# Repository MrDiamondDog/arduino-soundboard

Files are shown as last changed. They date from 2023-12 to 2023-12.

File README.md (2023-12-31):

# Arduino Soundboard

A soundboard made for an Arduino Mega 2560 that connects to your PC to adjust the volume of applications. 

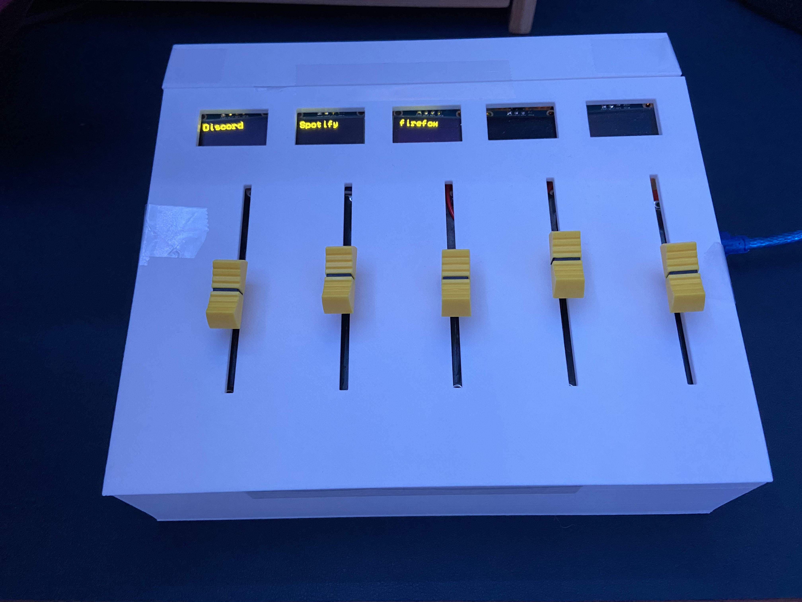
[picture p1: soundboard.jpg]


## How to make

There are a few steps required... and some money.

If you plan on making this, please read the whole document to fully understand what and how you are making this.

### Ingredients

-   3D Printer (for case)
-   Arduino Mega 2560
-   Breadboard
-   \>20x M/F Jumper Wires
-   5x [10K Logarithmic Slide Potentiometer](https://www.amazon.com/dp/B01CZVZ16O)
-   5x [0.96 inch 128x64 OLED LCD I2C Screens](https://www.amazon.com/dp/B085WCRS7C)
-   Constant USB connection to computer

### Steps

1. Clone this repo
2. Arduino Setup
    1. Install [Arduino IDE](https://www.arduino.cc/en/software)
    2. Open `arduino/arduino.ino` in the IDE
    3. Install all libraries from `arduino/libraries/`
        - To do this, use the IDE and navigate to `Sketch > Include Libraries > Add .ZIP Library...` and select the `.zip` files in the `libraries` folder.
    4. Connect the Arduino to your computer via USB
    5. Select the Arduino Mega 2560 and port in the IDE
    6. Upload the code to the Arduino
3. 3D Printing
    1. Download the STL file from [here](case.md)
    2. Print it (any color, any filament, it doesn't matter)
4. Assembly (this requires _some_ knowledge of electronics)
    1. Put the Arduino in the case, so the hole lines up with the port
    2. Adhere the back of your breadboard to the back inside part of the case
    3. Put all of the potentiometers (take off the caps) on the pedestals and adhere them to said pedsatals (I used tape)
    4. Wire all of the potentiometers to the arduino, where the first one is connected to A10, then second to A11, etc.
    5. Wire all of the potentiometers to power (5V) and ground on the breadboard.
    6. Adhere the screens to the holes (more tape)
    7. Wire all the screens so that the first one's SCL is connected to A0, SDA to A1, second one's SCL to A2, SDA to A3, etc.
    8. Connect the screens to power (5V) and ground on the breadboard.
    9. Adhere the screens to the lid (more tape)
    10. Put the lid on the case (this may require some force), make sure the potentiometers are in the holes
    11. Adhere the lid to the case (more tape)
    12. Almost there, put the caps on the potentiometers and put the small lid on the case
    13. Connect Arduino to computer via USB
5. PC Setup
    1. Install [Node.js](https://nodejs.org/en/) and make sure it came with `npm`
    2. Run `npm i` to install all required packages
    3. Copy `node_modules/@serialport/bindings-cpp/prebuilds` into `out` (make the out folder if it doesn't exist)
    4. Make sure your Arduino is connected to your computer via USB and running with the Arduino program
    5. Run `npm start` to start the program
    6. Make sure the program is working properly by moving the sliders and hearing the volume of the application change
6. Adding to start
    1. After running the commands from before and making sure it is working, run `npm run package` in your terminal.
    2. Change the path on the 3rd line of `soundboard_nogui.vbs` to the path of `out`.
    3. Put `soundboard_nogui.vbs` to your startup folder (Windows: `C:\Users\<user>\AppData\Roaming\Microsoft\Windows\Start Menu\Programs\Startup`)

### Additional Notes

-   You can change all of the values from `config.json`, you must restart after changing any heartbeat related values.
    -   `blacklistProcesses`: A list of processes to ignore, to add one, just add the exact name of the process from the soundboard to the array.
    -   `priorityProcesses`: A list of processes to give priority to, to add one, just add the exact name of the process from the soundboard to the array. This will move that process to the front.
    -   `heartbeatInterval`: The interval in milliseconds to send a heartbeat to the Arduino. This is used to make sure the Arduino is still connected.
    -   `heartbeatTimeout`: The timeout in milliseconds to wait for a heartbeat from the Arduino. If the Arduino does not send a heartbeat in this time, the program will re-open a connection to the Arduino.
-   The web panel is hosted on http://localhost:2345/, this lets you view the logs and stop/restart the backend.
-   To force-shut down the program, open task manager and find `Node.js JavaScript Runtime` (you may have to scroll a while), and end the task.
-   If the PC disconnects from the Arduino (the program stops), the soundboard will tell you.
-   If the PC is disconnected forcefully (unplugged), you will notice the soundboard will not tell you, but the program will stop working.
-   There is a `logs.txt` file where the executable is, it may get big if you leave it running for a while.
-   If a heartbeat fails (the Arduino is not responding), the program will try to reconnect to the Arduino. This takes a few seconds, so you may notice a delay in the volume changing.
-   This project is by no means perfect, this is just something fun I made in my free time. If you have any suggestions, feel free to open an issue or pull request.

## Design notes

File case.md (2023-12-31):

# The Case

Download these STL files and print them. Do not change the size of them or this won't work

-   [Base](stl/Soundboard_Base.stl)
-   [Small Top Part](stl/Soundboard_Top_Flat.stl)
-   [Large Top Part](stl/Soundboard_Top_Frame.stl)

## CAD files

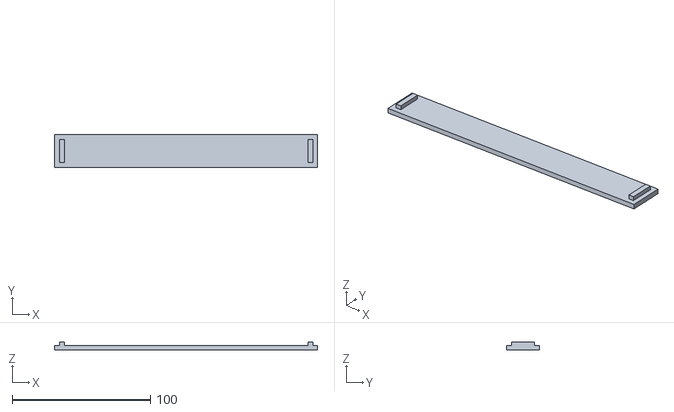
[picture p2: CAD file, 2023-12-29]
stl/Soundboard_Top_Flat.stl
190.5 x 23.8 x 5.84

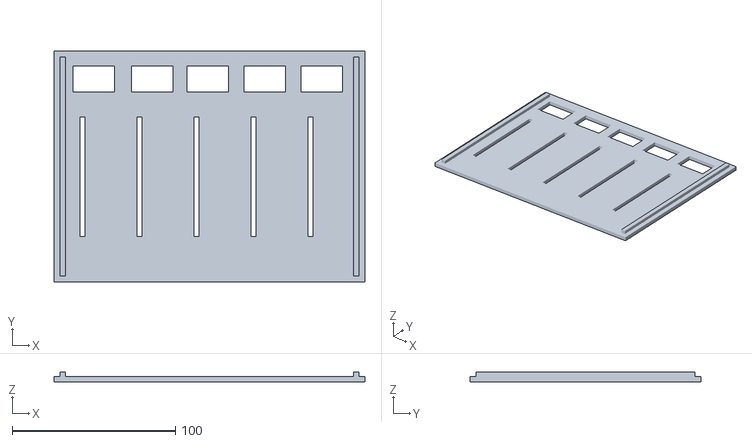
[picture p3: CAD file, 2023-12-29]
stl/Soundboard_Top_Frame.stl
190.5 x 141.4 x 5.84

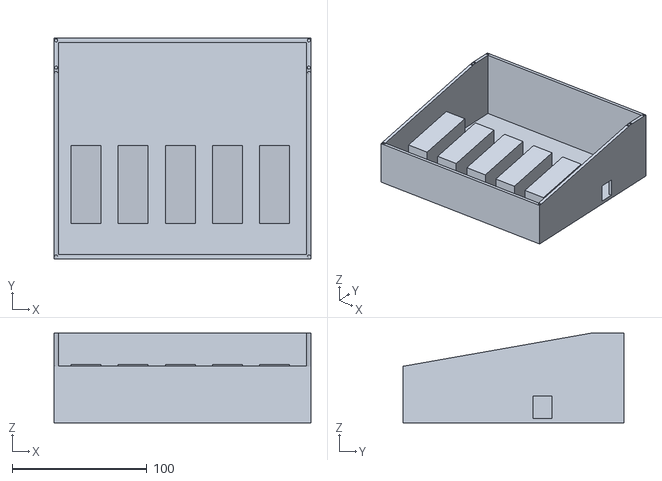
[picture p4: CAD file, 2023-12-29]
stl/Soundboard_Base.stl
190.5 x 163.5 x 66.7

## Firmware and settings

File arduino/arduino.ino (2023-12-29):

#include <OneBitDisplay.h>

#define NUM_DISPLAYS 5
#define OLED_SIZE OLED_128x64
#define FONT FONT_12x16
#define FONT_SMALL FONT_8x8

OBDISP obd[NUM_DISPLAYS];

bool ready = false;

class Fader {
public:
  int volume = 0;
  int id = 0;
  int pot = A0;
  char* name = "Empty";

  Fader(int id, int pot) {
    this->id = id;

    this->pot = pot;

    pinMode(pot, INPUT);
    volume = read();
  }

  int read() {
    return map(analogRead(pot), 0, 1023, 100, 0);
  }

  void updateVolume() {
    int newVal = read();

    if (newVal <= 3) newVal = 0;

    if (abs(volume - newVal) >= 2) {
      volume = newVal;
      if (Serial) sendUpdate();
    }
  }

  void updateScreen() {
    if (name == "Empty") {
      obdFill(&obd[id], 0x00, 1);
      return;
    }
    obdFill(&obd[id], 0x00, 1);
    obdWriteString(&obd[id], 0, 0, 0, name, FONT, 0xff, 1);
  }

  void sendUpdate() {
    if (name == "Empty") return;
    Serial.println("changevolume " + String(replaceString(name, " ", "_")) + " " + String(volume));
  }


  char* replaceString(const char* str, const char* find, const char* replace) {
    int findLen = strlen(find);
    int replaceLen = strlen(replace);
    int resultLen = strlen(str) + (replaceLen - findLen) * countOccurrences(str, find) + 1;

    char* result = new char[resultLen];
    result[0] = '\0';  // Initialize the result string as an empty string

    const char* pos = str;
    const char* prevPos = str;

    while ((pos = strstr(pos, find)) != nullptr) {
      strncat(result, prevPos, pos - prevPos);  // Append the portion before 'find'
      strcat(result, replace);                  // Append the replacement string
      prevPos = pos + findLen;                  // Move the previous position after the found substring
      pos = prevPos;                            // Move the current position after the found substring
    }

    strcat(result, prevPos);  // Append the remaining portion of the original string

    return result;
  }

  int countOccurrences(const char* str, const char* find) {
    int count = 0;
    const char* pos = str;

    while ((pos = strstr(pos, find)) != nullptr) {
      count++;
      pos += strlen(find);  // Move the position after the found substring
    }

    return count;
  }
};

Fader faders[5] = {
  Fader(0, A10),
  Fader(1, A11),
  Fader(2, A12),
  Fader(3, A13),
  Fader(4, A14)
};


#define RESET_PIN -1
// let ss_oled figure out the display address
#define OLED_ADDR -1
// don't rotate the display
#define FLIP180 0
// don't invert the display
#define INVERT 0
// Bit-Bang the I2C bus
#define USE_HW_I2C 0

uint8_t scl_list[NUM_DISPLAYS] = { A0, A2, A4, A6, A8 };
uint8_t sda_list[NUM_DISPLAYS] = { A1, A3, A5, A7, A9 };


int scroll = 0;

int backButton = 12;
int backButtonState;
int lastBackButtonState = LOW;
unsigned long backLastDebounceTime = 0;  // the last time the output pin was toggled
unsigned long backDebounceDelay = 50;    // the debounce time; increase if the output flickers

int forwardButton = 3;
int forwardButtonState;
int lastForwardButtonState = LOW;
unsigned long forwardLastDebounceTime = 0;  // the last time the output pin was toggled
unsigned long forwardDebounceDelay = 50;    // the debounce time; increase if the output flickers

void setup() {
  Serial.begin(9600);
  while (!Serial)
    ;

  pinMode(backButton, INPUT);
  pinMode(forwardButton, INPUT);

  int rc;

  for (int i = 0; i < NUM_DISPLAYS; i++) {
    rc = obdI2CInit(&obd[i], OLED_SIZE, OLED_ADDR, FLIP180, INVERT, 0, sda_list[i], scl_list[i], RESET_PIN, 100000L);

    Serial.print("Screen ");
    Serial.print(i);
    Serial.print(" started with code ");
    Serial.println(rc);

    if (rc != OLED_NOT_FOUND) {
      obdSetTextWrap(&obd[i], true);

      obdFill(&obd[i], 0x00, 1);

      // obdWriteString(&obd[i], 0, -1, -1, "Screen ", FONT, 0xff, 1);
      // char number[16];
      // itoa(i + 1, number, 10);
      // obdWriteString(&obd[i], 0, -1, -1, number, FONT, 0xff, 1);
    }
  }


  Serial.println("ready");
  while (!ready) {
    receiveData();
  }

  Serial.println("req processes " + String(scroll));
}

void loop() {
  for (int i = 0; i < sizeof(faders) / sizeof(faders[0]); i++) {
    faders[i].updateVolume();
  }

  int backReading = digitalRead(backButton);
  int forwardReading = digitalRead(forwardButton);

  if (backReading != lastBackButtonState) {
    // reset the debouncing timer
    backLastDebounceTime = millis();
  }

  if ((millis() - backLastDebounceTime) > backDebounceDelay) {
    // whatever the reading is at, it's been there for longer than the debounce
    // delay, so take it as the actual current state:

    // if the button state has changed:
    if (backReading != backButtonState) {
      backButtonState = backReading;

      // only toggle the LED if the new button state is HIGH
      if (backButtonState == HIGH) {
        scroll--;
        if (scroll < 0) scroll = 0;
        Serial.print("Back button ");
        Serial.println(scroll);

        Serial.print("req processes ");
        Serial.println(scroll);
      }
    }
  }


  if (forwardReading != lastForwardButtonState) {
    // reset the debouncing timer
    forwardLastDebounceTime = millis();
  }

  if ((millis() - forwardLastDebounceTime) > forwardDebounceDelay) {
    // whatever the reading is at, it's been there for longer than the debounce
    // delay, so take it as the actual current state:

    // if the button state has changed:
    if (forwardReading != forwardButtonState) {
      forwardButtonState = forwardReading;

      // only toggle the LED if the new button state is HIGH
      if (forwardButtonState == HIGH) {
        scroll++;
        Serial.print("Forward button ");
        Serial.println(scroll);

        Serial.print("req processes ");
        Serial.println(scroll);
      }
    }
  }

  receiveData();

  lastBackButtonState = backReading;
  lastForwardButtonState = forwardReading;
}

const char terminator = ';';
int dataIndex = 0;

void receiveData() {
  static String inputBuffer = ""; // Buffer to store received data

  // Check if there is data available to read
  while (Serial.available() > 0) {
    char incomingChar = Serial.read();

    // If the terminator character ";" is not received, add the character to the buffer
    if (incomingChar != terminator) {
      inputBuffer += incomingChar;
    }
    else {
      // Process the received data when the terminator character is received
      // For example, you can print it to the Serial monitor
      Serial.println("Received data: " + inputBuffer);

      parseCommand(inputBuffer.c_str());

      // Clear the buffer for the next data
      inputBuffer = "";
    }
  }
}

void parseCommand(char* receivedData) {
  if (startsWith(receivedData, "response")) {
    char* args = receivedData + 9;

    char** processes = splitString(splitString(args, " /")[0], "|");
    int len = atoi(splitString(args, "/")[1]);

    for (int i = NUM_DISPLAYS; i > len - 1; i--) {
      faders[i].name = "Empty";
      faders[i].updateScreen();
    }

    if (processes != nullptr) {
      for (int i = 0; i < len; i++) {
        if (processes[i] == nullptr) {
          break;
        }

        char* process = processes[i];

        Serial.print(i);
        Serial.print(" ");
        Serial.print("Process: '");
        Serial.print(process);
        Serial.println("'");

        faders[i].name = process;
        faders[i].updateScreen();
      }
    }
  }
  else if (startsWith(receivedData, "scroll")) {
    char* args = receivedData + 7;
    scroll = atoi(args);
  }
  else if (startsWith(receivedData, "ready")) {
    ready = true;
  }
  else if (startsWith(receivedData, "update processes")) {
    Serial.print("req processes ");
    Serial.println(scroll);
  }
  else if (startsWith(receivedData, "disconnect")) {
    Serial.println("Backend disconnected");

    char* args = receivedData + 11;

    for (int i = 0; i < NUM_DISPLAYS; i++) {
      obdFill(&obd[i], 0x00, 1);
    }

    obdWriteString(&obd[0], 0, -1, -1, "Backend", FONT, 0xff, 1);
    obdWriteString(&obd[1], 0, 0, 0, "Disconnect", FONT, 0xff, 1);
    obdWriteString(&obd[1], 0, 0, 32, args, FONT, 0xff, 1);
    obdWriteString(&obd[2], 0, -1, -1, "Move fader 0 to mute to shut off", FONT_SMALL, 0xff, 1);

    while (faders[0].volume != 0) {
      faders[0].updateVolume();
    }

    Serial.end();

    for (int i = 0; i < NUM_DISPLAYS; i++) {
      obdFill(&obd[i], 0x00, 1);
    }
  }
  else if (startsWith(receivedData, "disconnectinfo")) {
    char* args = receivedData + 15;

    obdWriteString(&obd[3], 0, -1, -1, args, FONT_SMALL, 0xff, 1);
  }
  else if (startsWith(receivedData, "heartbeat")) {
    Serial.println("heartbeat");
  }

  memset(receivedData, 0, sizeof(receivedData) / sizeof(receivedData[0]));
}





bool startsWith(const String& str, const String& prefix) {
  // Check if the prefix is longer than the input string
  if (prefix.length() > str.length()) {
    return false;
  }

  // Compare each character of the prefix and input string
  for (size_t i = 0; i < prefix.length(); i++) {
    if (str.charAt(i) != prefix.charAt(i)) {
      return false;
    }
  }

  return true;
}

char** splitString(const char* input, char* delimiter) {
  char** parts = nullptr;
  char* token;
  int numParts = 0;

  // Make a copy of the input string since strtok modifies the original string
  char inputCopy[strlen(input) + 1];
  strcpy(inputCopy, input);

  // Count the number of parts first
  token = strtok(inputCopy, delimiter);
  while (token != nullptr) {
    numParts++;
    token = strtok(nullptr, delimiter);
  }

  // Allocate memory for the array of pointers to split strings
  parts = (char**)malloc(numParts * sizeof(char*));
  if (parts == nullptr) {
    return nullptr;  // Memory allocation failed
  }

  // Reset the strtok pointer to split the string again
  strcpy(inputCopy, input);
  token = strtok(inputCopy, delimiter);
  int partIndex = 0;

  // Split the string and store the pointers to the split strings
  while (token != nullptr && partIndex < numParts) {
    parts[partIndex] = strdup(token);  // Duplicate the token string
    partIndex++;
    token = strtok(nullptr, delimiter);
  }

  return parts;
}
